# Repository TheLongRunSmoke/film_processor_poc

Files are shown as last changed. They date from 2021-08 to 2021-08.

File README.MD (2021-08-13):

English | [Русский](README.ru.MD)

# Film processor POC

POC prototype of film processor for developing drums like Jobo or any other watertight.

(https://www.youtube.com/watch?v=tWknhwFOHiI)



# Schematic

GND and 5v lines not shown, attach it Arduino, touch sensor and stepper driver.

Arduino ports can be remapped in [config.h](https://github.com/TheLongRunSmoke/film_processor_poc/blob/main/config.h)

              _________________________________________
             |                                         |
             |                                         |
             |             Arduino Nano v3             |
             |                                         |
             |_________________________________________|
                |    |    |                  | 
              D9|  D7|  D6|                D2|
                |    |    |                  |                  __________
                |    |    |                  |                 |          |
                |    |    |                  |_________Signal__|  TTP223  |
                |    |    |                                    |__________|
                |    |    |                  
                |    |    |              ______________    
                |    |    |__Enable_____|              |             
                |    |                  |    Pololu    |_______*         *
                |    |_______Direction__|     Step     |______*  Stepper  *
                |                       |    Driver    |______*   mottor  *
                |____________Step_______|              |_______*         *
                                        |______________|
                                            |      |
                                            ^ =12v ^

# BOM

I already had most of the parts, so prices approximate.

| Part | | Price  |
| ---|---:| ---:|
| Printed parts | | |
| Arduino Nano rev 3 |  |~6$|
| TTP223 touch sensor  | |~1$|
| Stepper driver interface board||~5$|
| DRV8825 or any other compatible driver || ~5$|
| NEMA17 or NEMA14 stepper motor ||~15$|
| GT2 450mm 6mm wide close timing belt | |~2$|
| 20T or 36T 8mm bore GT2 pulley X 2 ||~5$|
| 16T or 20T 5mm bore GT2 pulley ||~2$|
| LM2596 or any 5v step-down converter ||~3$|
| Any 12v 2-3A power source  | | ~10$ |  
| Any large enough container  | | |
| Any enclosure for electronic parts  | | |
| 200mm piece of 8mm stock X 2  | | |
| Assorted M3 and M4 hardware  | | |
| | Total: | ~60$ |

# Construction

You can drive developing drum in any way you want, even use a lift from Jobo processor if you find one.

Kinematic scheme of my prototype must be a pretty obvious by this picture. Place axis about 100 mm apart.



# Firmware

Easiest way to build and upload firmware is using Arduino IDE.

1. [Download](https://www.arduino.cc/en/software) and install Arduino IDE from official site.
2. Install FreeRTOS library using Sketch->Include library->Manage libraries... Type 'freertos' in search field, in first
   row select version 10.4.4-1 and click Install.
3. Select your board in Tool menu.
4. Click Upload.

# Calibration

Before using this construction you must set a number of motor steps per one full rotation of particular developing drum.

Manipulate value `RATIO` in [config.h](https://github.com/TheLongRunSmoke/film_processor_poc/blob/main/config.h) until
drum can make `TURNS` rotation without significant error.

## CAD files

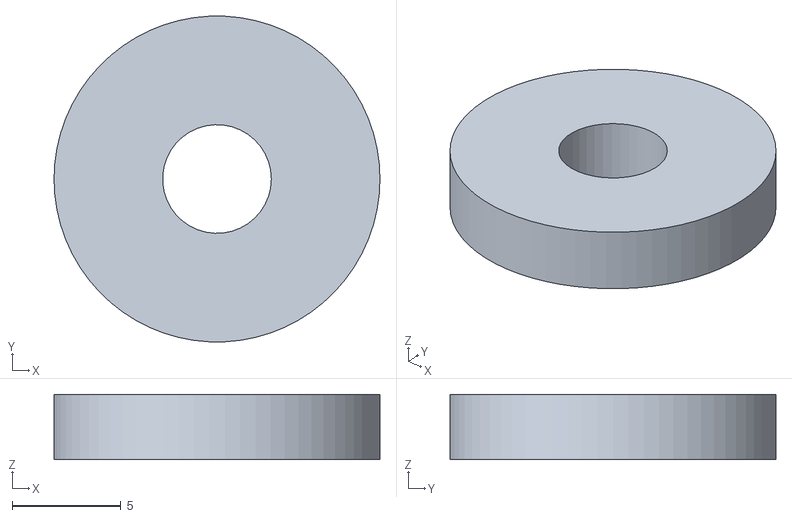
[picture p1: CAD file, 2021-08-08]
hardware/gasket.stl
15.0 x 15.0 x 3.00

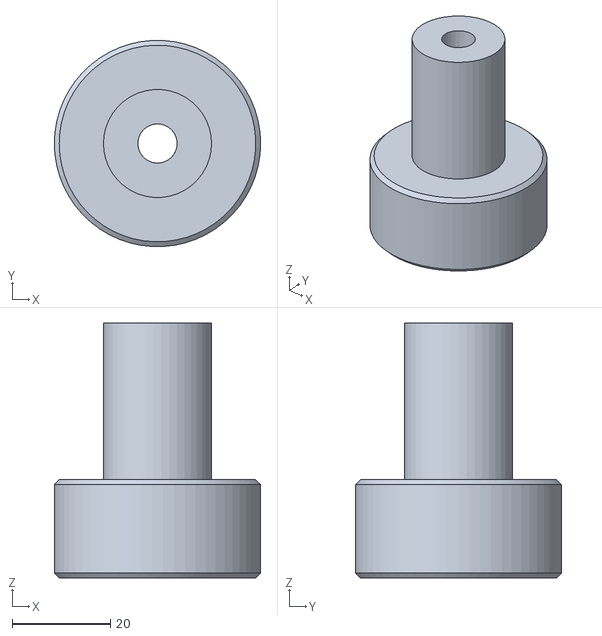
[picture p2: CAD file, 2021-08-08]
hardware/front_roll_first.stl
42.0 x 41.9 x 51.9

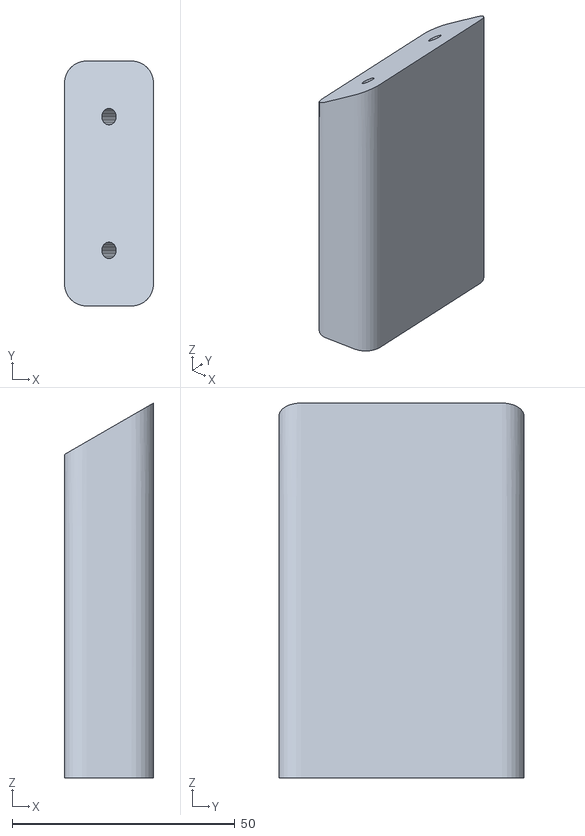
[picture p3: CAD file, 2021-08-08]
hardware/enclosure_bracket.stl
20.0 x 55.0 x 84.1

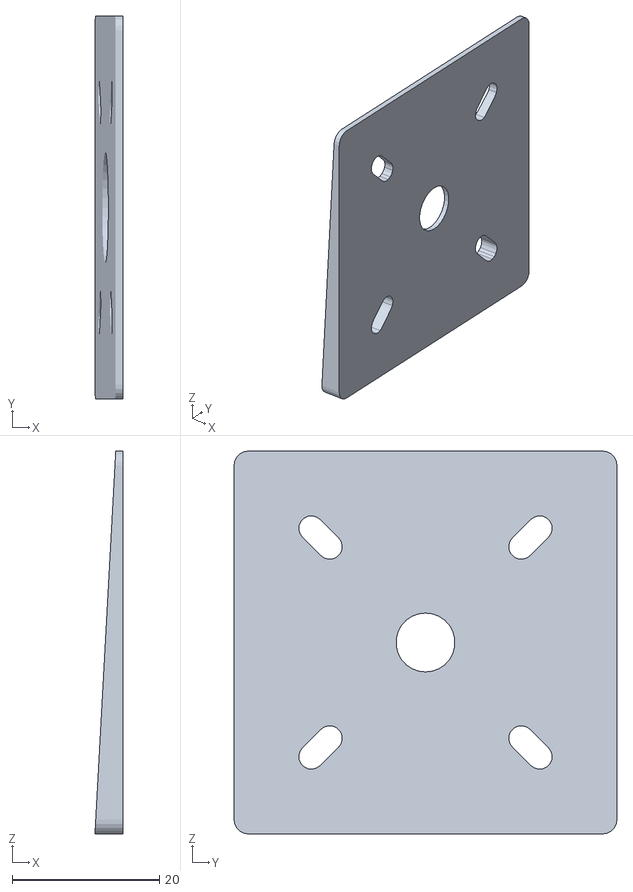
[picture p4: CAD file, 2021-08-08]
hardware/motor_mount_spacer.stl
3.82 x 52.0 x 52.0

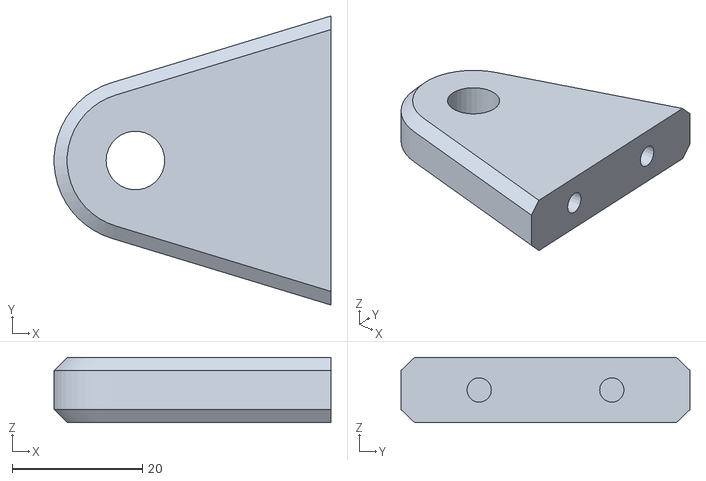
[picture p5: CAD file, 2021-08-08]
hardware/axis_mount.stl
42.5 x 44.4 x 10.0

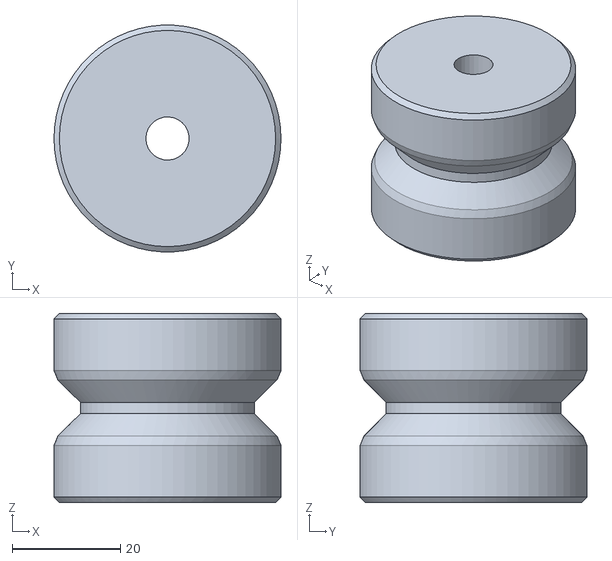
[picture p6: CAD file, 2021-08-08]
hardware/rear_roll.stl
42.0 x 41.9 x 35.0

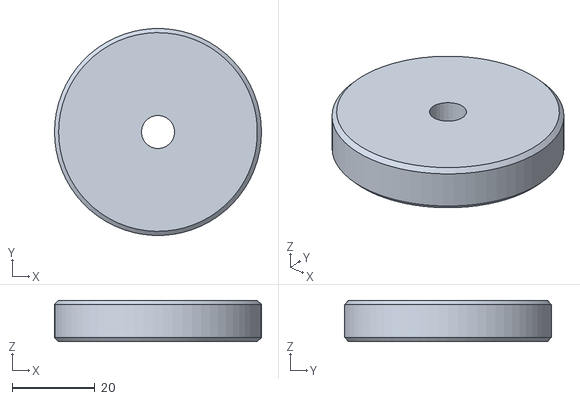
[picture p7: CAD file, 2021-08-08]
hardware/front_roll_second.stl
50.0 x 49.9 x 10.0

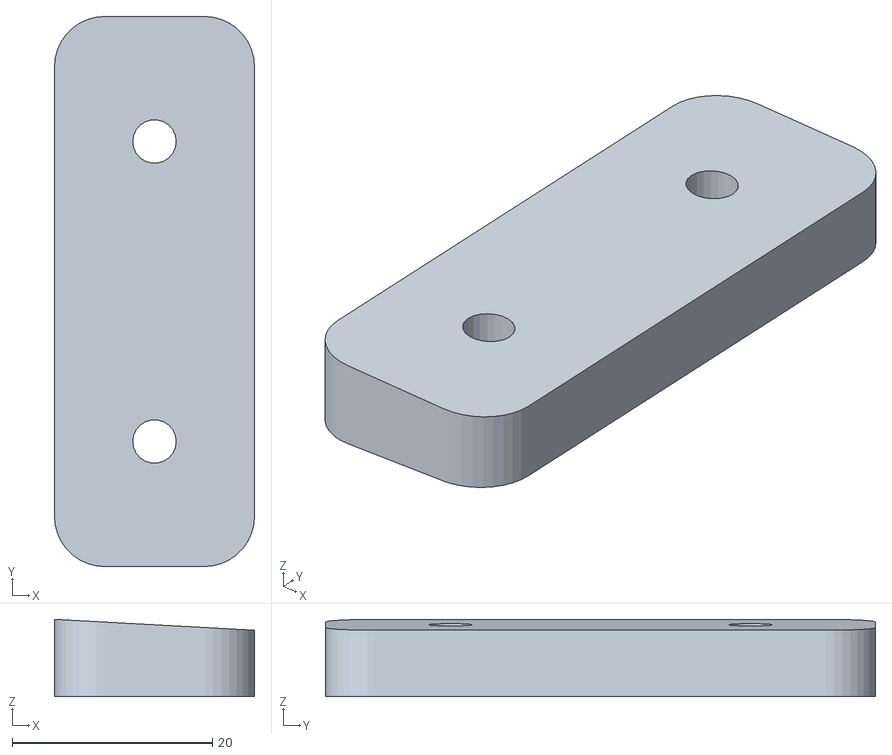
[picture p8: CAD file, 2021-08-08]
hardware/enclosure_bracket_spacer.stl
20.0 x 55.0 x 7.73

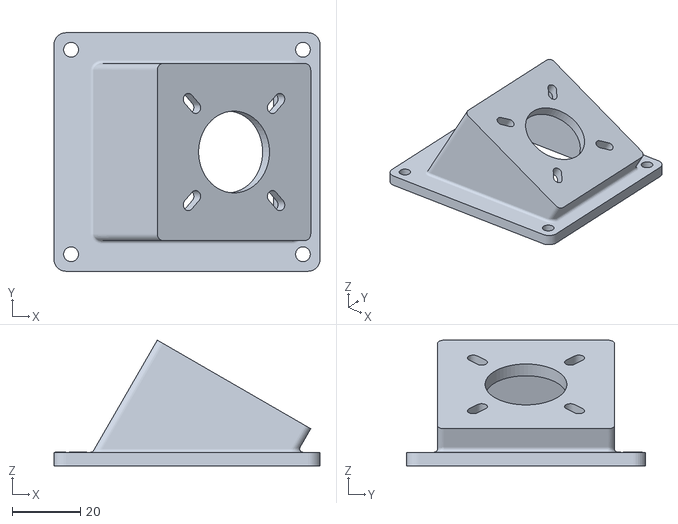
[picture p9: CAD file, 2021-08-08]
hardware/motor_mount.stl
78.0 x 70.0 x 36.9

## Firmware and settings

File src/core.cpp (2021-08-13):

#include "core.hpp"
#include "../config.h"
#include "tasks/input.hpp"
#include "tasks/indication.hpp"
#include "tasks/serial.hpp"
#include "tasks/motorcontroller.hpp"

// This object represents current system state.
State state{};

// Run system.
void setup() {
    // Check CPU speed.
    configASSERT(F_CPU == 16000000L);

    xTaskCreate(indication::task,
                indication::name,
                128,
                (void*) &state,
                configMAX_PRIORITIES - 2,
                nullptr);

    xTaskCreate(user_input::task,
                user_input::name,
                128,
                (void*) &state,
                configMAX_PRIORITIES - 2,
                nullptr);

    xTaskCreate(serial::task,
                serial::name,
                128,
                (void*) &state,
                configMAX_PRIORITIES - 2,
                nullptr);

    xTaskCreate(motor_controller::controlTask,
                motor_controller::controlTaskName,
                128,
                (void*) &state,
                configMAX_PRIORITIES - 2,
                nullptr);

}

void loop() {
    // Nothing to do here.
}

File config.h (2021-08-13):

#ifndef FILM_PROCESSOR_MINIMAL_CONFIG_H
#define FILM_PROCESSOR_MINIMAL_CONFIG_H

/**
 * Rotation mode.
 *
 * Main working mode, start/stop on action button press.
 * Rotate development tank with specified speed by specified number of turn in one direction than alternate.
 *
 * RATIO - number of motor steps to one rotation of development tank, see calibration section fore details.
 * SPEED - number of turns per minute for tank.
 * TURNS - number of turns in one direction.
 */
#define RATIO 855
#define RPM 60
#define TURNS 3

/**
 * Buttons configuration.
 *
 * POC has only one TTP223 button, active level high.
 */
#define ACTION_BUTTON_PIN 2
#define ACTION_BUTTON_ACTIVE_LEVEL HIGH

/**
 * Stepper motor configuration.
 *
 * STEP_PIN use PWM output! Do not touch it, unless you know what you doing.
 */
#define STEP_PIN 9
#define DIRECTION_PIN 7
#define ENABLE_PIN 6
#define MICROSTEP_MODE 2

/**
 * S-curve config.
 *
 * System use sigmoid function to accelerate and decelerate stepper.
 * If you have problems with chattering try to adjust motor current first.
 *
 * ELASTIC how fast motor accelerate, normally it must be between 4.0 and 6.0. Decrease to prevent chattering.
 * RAMP how long motor accelerate. Part of one turn. Increase to prevent chattering.
 */
#define ELASTIC 4.0
#define RAMP 0.25


#endif //FILM_PROCESSOR_MINIMAL_CONFIG_H

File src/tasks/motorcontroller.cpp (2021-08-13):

#include "motorcontroller.hpp"

void motor_controller::controlTask(void* pvParameters) {
    auto* state = (State*) pvParameters;
    TaskHandle_t motorTask = nullptr;
    for (;;) {
        if (state->isRunning && motorTask == nullptr) {
            xTaskCreate(motor_controller::reciprocatingSCurveTask,
                        motor_controller::reciprocatingSCurveTaskName,
                        128,
                        nullptr,
                        configMAX_PRIORITIES - 2,
                        &motorTask);
        } else if (!state->isRunning && motorTask != nullptr) {
            vTaskDelete(motorTask);
            motorTask = nullptr;
            clear();
        }
        vTaskDelay(50 / portTICK_PERIOD_MS);
    }
}

/**
 * Macro-style interrupt handler, to prevent any empty interrupt problem.
 */
ISR(TIMER1_OVF_vect){
        motor_controller::handlePwmCycle();
}

void motor_controller::handlePwmCycle() {
    noInterrupts();
    currentStep++;
    sCurve();
    // Alternate rotation direction if target number of steps reached.
    if (currentStep > targetStepNumber) {
        currentStep = 0;
        digitalWrite(DIRECTION_PIN, !digitalRead(DIRECTION_PIN));
    }
    interrupts();
}

void motor_controller::reciprocatingSCurveTask(void* pvParameters) {
    (void) pvParameters;
    config();
    currentStep = 0;
    // Compute all const parameters.
    targetStepNumber = RATIO * TURNS * MICROSTEP_MODE;
    targetFreq = (RPM / 60.0 * RATIO) * MICROSTEP_MODE;
    freqDelta = targetFreq - minFreq;
    // We have nothing to do here, so let scheduler visit this task less often.
    for (;;) {
        vTaskDelay(100 / portTICK_PERIOD_MS);
    }
}

void motor_controller::sCurve() {
    elastic = -ELASTIC;
    unsigned long step = currentStep;
    // Correct parameters if it's time to decelerate.
    if (currentStep > targetStepNumber - (long) (accelRamp * 2)) {
        elastic = -elastic;
        step = currentStep - (targetStepNumber - (long) (accelRamp * 2));
    }
    uint16_t currentFreq = minFreq + freqDelta / (1 + exp(elastic * (step - accelRamp) / accelRamp));
    ICR1 = F_CPU / currentFreq;
    // Pololu compatible driver typically need ~2us impulse to generate a step.
    float dutyCycle = 2e-6 / (1.0 / currentFreq);
    OCR1A = ICR1 * dutyCycle + 1;
}

void motor_controller::clear() {
    noInterrupts();
    digitalWrite(ENABLE_PIN, HIGH);
    digitalWrite(DIRECTION_PIN, LOW);
    TCCR1A = 0;
    TCCR1B = 0;
    TIMSK1 = 0;
    TCNT1 = 0;
    digitalWrite(STEP_PIN, LOW);
    interrupts();
}

void motor_controller::calibrationTask(void* pvParameters) {
    auto* state = (State*) pvParameters;
    // Omitted for now.
}

void motor_controller::config() {
    noInterrupts();
    // Configure output pins.
    pinMode(ENABLE_PIN, OUTPUT);
    pinMode(DIRECTION_PIN, OUTPUT);
    digitalWrite(DIRECTION_PIN, LOW);
    pinMode(STEP_PIN, OUTPUT);
    // Reset and configure timer.
    TCCR1A = 0;
    TCCR1B = 0;
    TIMSK1 = 0;
    TCNT1 = 0;
    // On Atmega 328 it's mode 14, no prescaling.
    TCCR1A = (1 << COM1A1) | (1 << WGM11);
    TCCR1B = (1 << WGM12) | (1 << WGM13) | (1 << CS10);
    // ICR1 now is timer top, set it to max.
    ICR1 = 0xFFFF;
    // OCR1A set to small safe value.
    OCR1A = ICR1 * 0.02;
    // Enable overflow interrupt.
    TIMSK1 = (1 << TOIE1);
    // Power driver output. Set this to HIGH if you need to test something without motor moving.
    digitalWrite(ENABLE_PIN, LOW);
    interrupts();
}

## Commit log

2021-08-10 Schematic and BOM added
2021-08-13 Calibration added in README
